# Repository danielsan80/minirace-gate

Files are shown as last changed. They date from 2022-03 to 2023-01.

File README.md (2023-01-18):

# Mini Race Challenge 3D printable parts

## Intro
This repository contains the 3D printable parts of the **Mini Race Challenge** Timing System.

It is a timing system specifically designed for extremely small sized radio controlled cars,
from 1:76 (Turbo Racing) to 1:57 (Coke Can Cars) and more.

More details on the site [www.miniracechallage.com](https://www.miniracechallenge.com).

The app is available at [app.miniracechallage.com](https://app.miniracechallenge.com)
and works on PC, IOS and Android.

This repository contains a few projects.

The project `gate` depends on the other ones.

`startlights` and `controller-box` are stand alone projects.

`ruler` and `car` are utilities.

## Contexts
The projects use a kind of framework.
You can find some directories that define the context:
- `src`: It contains the source code (*.scad) in an abstract/generic/default context.
  The 3d parts are located in a useful and natural position without a specific purpose.  
- `sim`: It contains modules useful for the simulation. These modules wrap and transform the source modules
  to translate and rotate them for a better placement in the space for a simulation purpose.
- `print`: It contains modules useful for the printing. These modules wrap and transform the source modules
  to translate and rotate them for a better placement in the space for a printing purpose.
- `test`: It contains modules useful for the testing. These modules cut or reduce the source
  modules to print drafts to test joints, plays, friction between parts and other test stuff.
  
## Conventions

Not all projects and parts still adopt the following conventions, but they are proving useful. 

### Private modules
To indicate a "private" module that is used only in the same file, it is prefixed with an underscore `_`.

A private module has a global scope too (with risk of name collision), but it helps to identify which modules in a file
should be considered "exported" and usable from who "< use >" the file.

### Context prefix
To specify a module belongs to a context it is prefixed with the context keyword (`print_*`, `sim_*`, `test_*`, ...).

### _transform suffix
To specify a module help to place a model in the right position (for a specific context for example)
it is suffixed with `_transform`. Obviously it has a `children()` instruction to which apply the transformation.

### _color suffix
To specify a module apply a color to a model (for a simulation for example)
it is suffixed with `_color`. Obviously it has a `children()` instruction to which apply the color.

# Index

[`controller-box`](controller-box/README.md): is the box to contain the controller card.

[`startlights`](startlights/README.md): Provides cover and hanger for the startlights card.
It provides a generic clip to hang the startlights and a metaclip to build a specific clip.

[`gate`](gate/README.md): Assembles the gate and the startlights together to simulate
and build the printable parts in stl files.
It adds the joint to hang up the startlights on the traverse.
It uses the rules to show the measures in the simulation context.
It uses the car models (1:54) to show the aspect ratio of the gate in the simulation context.

[`ruler`](ruler/README.md): is an utility to show rulers with some measures in simulation context.

[`car`](car/README.md): is an utility to show some cars in simulation context.

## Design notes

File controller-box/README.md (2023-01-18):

# Mini Race Challenge 3D printable parts: CONTROLLER BOX

This project provide the box to contain the controller.

The controller is the main timing system module card
to detect the passage of the cars on the start line.

## Getting started: easy way

Install [OpenSCAD](https://openscad.org/)

Download the project (Code -> Download ZIP) from [GitHub repository](https://github.com/danielsan80/minirace-gate).

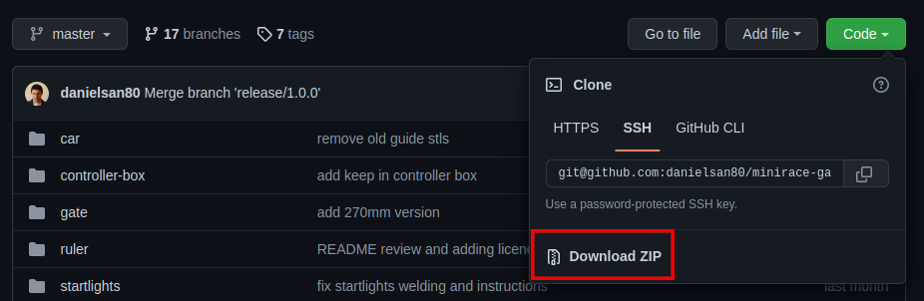
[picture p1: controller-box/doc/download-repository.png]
Download the project


Unzip the project in a directory (`<project-dir>`).

Find and open with OpenSCAD or with a text editor the file `<project-dir>/controller-box/config/parameters.scad`.

Change the parameters.

> for example your 3D printer may need a different play so you could change the `card_play`
> or any other `*_play` parameter.

After changing some parameter you can open with OpenSCAD the files in `<project-dir>/controller-box/build/scad/print`.

Then render the model (Design -> Render [F6]) and export it as STL (File -> Export -> Export as STL [F7])

That's all. Enjoy!

## Getting started: easy way for Linux users

Tested on Ubuntu 20.04.

You must have OpenSCAD (>=2019.05), ImageMagick and Git installed:

```
sudo apt-get install openscad imagemagick git
```

To build the gate you have to clone this project:

```
git clone git@github.com:danielsan80/minirace-gate.git
```

Enter the project dir:

```
cd minirace-gate
```

Enter in `controller-box` subdir:

```
cd controller-box
```

Now all should be ok.

### Rendering
The `<project-dir>/controller-box/build/scad/sim/*.scad` files are used to show a simulation of the whole controller box
and to generate the preview images.
You can play with these files or with a copy of them.

It is worth to grasp the whole idea.

The `<project-dir>/gate/build/scad/print/*.scad` files contain the single printable parts
and are used to generate the `*.stl` files at build time.

### Build

It's time to build the .stl files from the .scad files.

Run the build script:

```
bin/build
```

At the end of the build script running, you should have a new directory `<project-dir>/controller-box/build/stl`
with all updated .stl files

If you have to rebuild them you can clean up the build dir running

```
bin/cleanup
```

and rerun the `bin/build` script.

The dir `<project-dir>/gate/build/scad/print` contains the .scad version of the generated .stl files.

### Configuration

If you need to change the configuration you can edit the `gate/config/parameters.scad` file.

I tried to put all values in a parameter in this file. Tha major part of them should be considered as constants.

It makes sense to change only a few of them.

### Printing

I added a little [Printing guide](doc/printing.md) to help you to print the controller box.

The guide refers to the Thingiverse built .stl files.

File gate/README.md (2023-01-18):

# Mini Race Challenge 3D printable parts: GATE

This project assembles the gate and the startlights to simulate
and build the printable parts in stl files.
It adds the joint to hang up the startlights on the traverse.
It uses the rules to show the measures in the simulation context.
It uses the car models (1:54) to show the aspect ratio of the gate in the simulation context.

## Getting started: easy way

Install [OpenSCAD](https://openscad.org/)

Download the project (Code -> Download ZIP) from [GitHub repository](https://github.com/danielsan80/minirace-gate).

Download the project

Unzip the project in a directory (`<project-dir>`).

Create a link `<project-dir>/gate/vendor` -> `<project-dir>` 

Find and open with OpenSCAD or with a text editor the file `<project-dir>/gate/config/parameters.scad`.

Change the parameters.

> for example if you want to change the length of the traverse,
you must change the `startline_l` parameter, setting the distance (in millimeters) between the basements.

After changing some parameter you can open with OpenSCAD one of the files in `<project-dir>/gate/build/scad/print`.

> if you have changed the `startline_l` parameter you probably want to obtain the new stl traverse files:
> so open `<project-dir>/gate/build/scad/print/gate/traverse/traverse.scad`
> or one of his variants in `.../print/gate/traverse/variant/**/*.scad`.
 
Then render the model (Design -> Render [F6]) and export it as STL (File -> Export -> Export as STL [F7])

That's all. Enjoy!

## Getting started: easy way for Linux users

Tested on Ubuntu 20.04.

You must have OpenSCAD (>=2019.05), ImageMagick ang Git installed:

```
sudo apt-get install openscad imagemagick git
```

To build the gate you have to clone this project:

```
git clone git@github.com:danielsan80/minirace-gate.git
```

Enter the project dir:

```
cd minirace-gate
```

### Setup
After cloning the project from Github and moving into the project dir you must setup the project.

Enter in `gate` subdir:

```
cd gate
```

Run the setup script:

```
bin/setup
```

Now all should be ok.

### Rendering
The `<project-dir>/gate/build/scad/sim/*.scad` files are used to show a simulation of the whole gate
and to generate the preview images.
You can play with these files or with a copy of them.

It is worth to grasp the whole idea.

The `<project-dir>/gate/build/scad/print/*.scad` files contain the single printable parts
and are used to generate the `*.stl` files at build time. 

### Build

It's time to build the .stl files from the .scad files.

Run the build script:

```
bin/build
```

At the end of the build script running, you should have a new directory `gate/build/stl`
with all updated .stl files

If you have to rebuild them you can clean up the build dir running

```
bin/cleanup
```

and rerun the `bin/build` script. 

The dir `<project-dir>/gate/build/scad/print` contains the .scad version of the generated .stl files. 

### Configuration

If you need to change the configuration you can edit the `gate/config/parameters.scad` file.

I tried to put all values in a parameter in this file. Tha major part of them should be considered as constants.

It makes sense to change only a few of them. 

### Printing

The project has a lot of elements, so I added a little [Printing guide](doc/printing.md) to help you understanding it.

The guide refers to the Thingiverse built .stl files.

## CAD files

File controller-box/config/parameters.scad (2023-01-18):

$fn = 100;
fix = 0.01;
fix2 = 0.1;
a_lot = 1000;
a_few = 10;
layer_w = 0.46;
layer_h = 0.15;

box_wall_thick = 2.2;
box_wall_half_thick = box_wall_thick/2;
box_bottom_base_thick = 1;
box_top_base_thick = 1;

box_joint_h = 4;

box_joint_play = 0.20;
box_side_slide_play = 0.15;
box_joint_half_play = box_joint_play/2;

card_w = 36.5;
card_l = 83.5;
card_thick = 0.6;
card_z_offset = 1;
card_play = 0.25;
card_overhang_l = 8;
card_overhang_offset = 4.5;
card_overhang_w = 31;
card_left_margin = 2;
card_back_margin = 2;

chip_x = card_overhang_l+4;
chip_y = -8;
chip_l = 44+(chip_y*-1);
chip_w = 28;
chip_thick = 3.8 + 0.4;
chip_play = 0.3;
chip_z_offset = 0;//8.4;

card_keep_l = (card_w-chip_w)/2-chip_play*2;
card_central_keep_r = 2;

chip_connector_w = 7.5;
chip_connector_l = 5;
chip_connector_h = 2.8;
chip_connector_plugin_w = 10;
chip_connector_plugin_h = 7;

chip_connector_hole_frame_thick = 0.6;
chip_connector_hole_margin_w = 0.5;
chip_connector_hole_margin_h = 0.5;
chip_connector_hole_w = chip_connector_w+chip_connector_hole_margin_w*2;
chip_connector_hole_h = chip_connector_h+chip_connector_hole_margin_h*2;
chip_connector_hole_thick = 1.6;

chip_connector_inner_niche_margin_w = 0.5;
chip_connector_inner_niche_margin_h = 0.5;
chip_connector_inner_niche_w = chip_w+chip_connector_inner_niche_margin_w*2;
chip_connector_inner_niche_h = chip_thick+chip_connector_h+chip_connector_inner_niche_margin_h*2;
chip_connector_inner_niche_offset = 0.5;

chip_connector_outer_niche_margin_w = 0.5;
chip_connector_outer_niche_margin_h = 0.5;
chip_connector_outer_niche_w = chip_connector_plugin_w+chip_connector_outer_niche_margin_w*2;
chip_connector_outer_niche_h = chip_connector_plugin_h+chip_connector_outer_niche_margin_h*2;
chip_connector_outer_niche_offset = chip_play-chip_connector_inner_niche_offset+box_wall_thick-chip_connector_hole_thick;

chip_processor_w = 20;
chip_processor_l = 20;
chip_processor_thick = 7-chip_thick;
chip_processor_margin = 5;

startlights_connector_w = 3.6;
startlights_connector_l = 7.2;
startlights_connector_h = 5;
startlights_connector_pos = [card_overhang_l,43.31];

startlights_connector_old_w = 3.6;
startlights_connector_old_l = 10;
startlights_connector_old_h = 5;
startlights_connector_old_pos = [card_overhang_l,-startlights_connector_old_l/2+card_l-card_overhang_offset-card_overhang_w-4];

antenna_w = card_overhang_w;
antenna_play = 0.5;
antenna_thick = 0.5;
antenna_hole_thick = 1;
antenna_hole_w = antenna_w+antenna_play*2;
antenna_side_margin = card_overhang_offset;
antenna_start_margin = 2;
antenna_end_l = 15;
antenna_l = 198-antenna_end_l;

antenna_guide_thick = box_wall_half_thick;
//antenna_guide_side_margin = antenna_side_margin-antenna_play;
antenna_guide_play = antenna_play;
antenna_guides_gap_w = antenna_hole_w;
antenna_guides_gap_side_offset = card_left_margin+card_play+antenna_side_margin-antenna_play;



box_inner_l = card_left_margin+card_l+(chip_y*-1)+card_play+chip_play-chip_connector_inner_niche_offset;
box_inner_h = card_z_offset+card_thick+chip_z_offset+chip_thick+chip_connector_h+box_joint_h+chip_connector_hole_margin_h+chip_connector_hole_frame_thick;

box_outer_l = box_inner_l + box_wall_thick*2;
box_outer_h = box_inner_h + box_bottom_base_thick + box_top_base_thick;

box_inner_w = card_back_margin+card_w+card_overhang_l+antenna_start_margin+card_play*2;
box_outer_w = box_inner_w + box_wall_thick*2;

// CHIP LEDS

chip_led_hole_d = 4.5;
chip_led_hole_cap_d = 5;
chip_led_hole_cap_r = chip_led_hole_cap_d/2;
chip_led_hole_cap_inner_thick = 0.8;
chip_led_hole_cap_play = 0.12;
chip_led_hole_r = chip_led_hole_d/2;

chip_led_hole_tube_thick = 1;
chip_led_hole_tube_r = chip_led_hole_r+chip_led_hole_tube_thick;
chip_led_hole_tube_r_ext = 0.5;
chip_led_hole_tube_h1 = 3;
chip_led_hole_tube_h2 = 3.5;


// CHIP BLUE LED
chip_blue_led_hole_angle_pos = [-18,24];
chip_blue_led_hole_angle_pos_offset = [
    -chip_w-chip_x-card_play-antenna_start_margin-box_wall_thick+box_outer_w,
    -chip_y+card_l+card_play+card_left_margin+box_wall_thick-box_outer_l
];

chip_blue_led_angle_pos = [
    chip_blue_led_hole_angle_pos.x+chip_blue_led_hole_angle_pos_offset.x,
    chip_blue_led_hole_angle_pos.y+chip_blue_led_hole_angle_pos_offset.y
    ];



// CHIP RED LED
chip_red_led_hole_angle_pos = [
    chip_blue_led_hole_angle_pos.x-9.525,
    chip_blue_led_hole_angle_pos.y
];
chip_red_led_hole_angle_pos_offset = [
    -chip_w-chip_x-card_play-antenna_start_margin-box_wall_thick+box_outer_w,
    -chip_y+card_l+card_play+card_left_margin+box_wall_thick-box_outer_l
];

chip_red_led_angle_pos = [
    chip_red_led_hole_angle_pos.x+chip_red_led_hole_angle_pos_offset.x,
    chip_red_led_hole_angle_pos.y+chip_red_led_hole_angle_pos_offset.y
];


cylinder_joint_play = 0.20;
cylinder_joint_margin = 6;
cylinder_joint_r = 0.5;


nail_groove_margin = 6;
nail_groove_r = 0.5;

keep_w = 1;
keep_wall_thick= max(card_back_margin, card_left_margin); //1;
keep_h = card_z_offset;
keep_card_thick_play = 0.2;
keep_card_thick = card_thick+keep_card_thick_play;
keep_hold_r = 0.4;

box_front_center_keep_offset = [0,-1];

box_card_pos = [
    box_wall_thick+antenna_start_margin+card_play,
    box_wall_thick+(chip_y*-1)+chip_play-chip_connector_inner_niche_offset,
    box_bottom_base_thick+card_z_offset
];


startlights_cable_side_hole_w = 3;
startlights_cable_side_hole_h = 3;
startlights_cable_side_hole_pos = [box_card_pos.y+startlights_connector_pos.y,box_outer_h-box_top_base_thick-startlights_cable_side_hole_h/2-1];
//startlights_cable_side_hole_pos = [box_outer_l/2, box_outer_h/2];
startlights_cable_side_hole_play = box_joint_play;

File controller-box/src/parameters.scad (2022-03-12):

$fn = 100;
fix = 0.01;
fix2 = 0.1;
a_lot = 1000;
play1 = 0.15;
play2 = 0.20;
play3 = 0.25;

box_wall_thick = 2.2;
box_wall_half_thick = box_wall_thick/2;
box_bottom_base_thick = 1;
box_top_base_thick = 1;

box_joint_h = 4;

card_w = 44.5;
card_l = 91.5;
card_thick = 0.6;
card_z_offset = 2;
card_play = play1;

antenna_w = 35;
antenna_thick = 1.5;
antenna_side_margin = 3.5;

box_inner_w = card_w+card_play*2;
box_inner_l = card_l+card_play*2;
box_inner_h = 10;
//box_inner_w = 4;
//box_inner_l = 30;
//box_inner_h = 10;

box_outer_w = box_inner_w + box_wall_thick*2;
box_outer_l = box_inner_l + box_wall_thick*2;
box_outer_h = box_inner_h + box_bottom_base_thick + box_top_base_thick;

box_joint_play = play2;
box_side_slide_play = play1;
box_joint_half_play = box_joint_play/2;

cylinder_joint_play = play2;
cylinder_joint_margin = 6;
cylinder_joint_l = box_inner_w - cylinder_joint_margin*2 ;
cylinder_joint_r = 0.4;


nail_groove_margin = 6;
nail_groove_l = box_inner_w - nail_groove_margin*2 ;
nail_groove_r = 0.5;

rail_bottom_w = 1;
rail_top_right_r = 0.4;
rail_top_left_r = 0.15;

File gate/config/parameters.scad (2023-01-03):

$fn=100;
fix = 0.01;
fix2 = 0.1;
a_lot = 1000;
a_few = 10;
play = 0.25;
play2 = 0.15;
play3 = 0.20;
    layer_h = 0.15;
    layer_w = 0.46;
min_space = 0.198;

profile_w = 20;
profile_h = 2;

base_curvature_r = 2;

upright_base_w = 20;
upright_base_l = 47;
upright_base_h = 2.5;

angle_base_w = 20;
angle_base_l = 25;
angle_base_h = 2.5;
angle_base_h2_c = 0.5;

base_hole_margin = 0.3;

pylon_side = 13;

bar_w = 4;

bolt_d=6;
bolt_h=4;


reinforcement_gap = 5;
//reinforcement_gap = -5;

startline_l = 160; //80; //160; //270;
startline_l_160mm = 160;
startline_l_270mm = 270;

upright_h = 90; //40; //90;

upright_base_groove_thick = min_space;
upright_base_groove_depth = layer_h*2;
upright_base_hole_play = 0.15;

basement_upright_margin = 5;
basement_h = 10;

traverse_play = play2;

traverse_hook_l = 8;
traverse_hook_w = 2;
traverse_hook_thick = 0.8;
traverse_hooks_intra_space_l = 30;

bar_wrapper_w = 3;
bar_wrapper_thick = 1.2;
bar_wrapper_play = play2;

traverse_bar_wrappers_intra_space_l = (reinforcement_gap+pylon_side)*2;

ct_slide_side = 7;
ct_slide_play = play3;

v_slide_play = play2;

hanger_clip_junction_w = 2;
hanger_clip_junction_l = 4;

hanger_clip_generic_w = 5;

bolt_joint_play = 0.15;

stick_void_l_margin = 0.5;
stick_d = 2;
stick_play = 0.15;

traverse_stick_l = 30;
traverse_stick_void_l = traverse_stick_l + stick_void_l_margin*2;

upright_angle_joint_stick_l = 15;
upright_angle_joint_stick_void_l = upright_angle_joint_stick_l + stick_void_l_margin;

upright_angle_joint_button_r = bar_w/2;
upright_angle_joint_button_play = 0.25;
upright_angle_joint_button_h = 3;
upright_angle_joint_bar_top_w = 1;
upright_angle_joint_bar_top_play = 0.15;
upright_angle_joint_bar_bottom_h = angle_base_h*angle_base_h2_c;


bolting_base_thick = 0.5;

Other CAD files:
gate/src/parameters.scad
car/main.scad
car/src/car.scad
car/src/cars.scad
controller-box/build/scad/print/box/box_bottom.scad
controller-box/build/scad/print/box/box_side_slide.scad
controller-box/build/scad/print/box/box_top.scad
controller-box/build/scad/print/box/box_top_led_hole_cap.scad
controller-box/build/scad/sim/controller-box.scad
controller-box/main.scad
controller-box/src/functions.scad
controller-box/src/interparts/box_bottom-box_side_slide.scad
controller-box/src/interparts/box_bottom-box_top.scad
controller-box/src/joints/cylinder_joint.scad
controller-box/src/joints/keep.scad
controller-box/src/joints/nail_groove.scad
controller-box/src/parts/box_bottom.scad
controller-box/src/parts/box_side_slide.scad
controller-box/src/parts/box_top.scad
controller-box/src/parts/box_top_led_hole_cap.scad
controller-box/src/parts/print/box_bottom.scad
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

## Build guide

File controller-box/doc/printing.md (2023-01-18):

## Printing guide

### Intro

These are the main parts of the project:

- the controller box
- the led caps

Of course you can use the filament colors you prefer but
ideally the project is designed to be printed with this ones:

- **matte black** for the controller box
- **transparent** for the led caps

Here are some suggestions:

- **matte black**:  [Overture Matte Black pla filament](https://www.amazon.it/gp/product/B08X6YWZBT) [★★★★★].
- **transparent**:  [Giantarm Transparent pla filament](https://www.amazon.it/gp/product/B08LZ7L7L1) [★★★★☆]. You can avoid to print the led caps and use these [LED lampshade with light guide column cap](https://www.aliexpress.com/item/1005002316760848.html)

**No supports are needed**.

### Controller box

Printing the controller box is **the only thing required** to get started with MRC Timing system.

- box_bottom.stl (x 1) [**matte black**]
- box_side_slide.stl (x 1) [**matte black**]
- box_top.stl (x 1) [**matte black**]
- box_top_led_hole_cap (x 2) [**transparent**]

That's all!

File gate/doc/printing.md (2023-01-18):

## Printing guide

### Intro

These are the main parts of the project:

- the basements (blocks to place the gate on)
- the gate (uprights, angles and traverse)
- the boltings (bolts help you to place the gate on something other than the basements)
- the starglights (the cover to put on the startlights module)
- the hanger (clips and rod allow you to hang up the startlights module on the gate traverse).

Of course you can use only one filament colors and in case paint it but
ideally the project is designed to be printed in different ones:

- **cement gray** for the basements
- **silver** for the gate, the hanger clips and the boltings
- **matte black** for the startlights cover and the hanger rod

Here are some suggestions:

- **cement gray**: [Giantarm Silver pla filament](https://www.amazon.it/Filamento-GIANTARM-Stampante-Spool-Argento/dp/B07PV5KD6S) [★★★★☆]. It is a silver, not a gray, but we like it and is a good quality brand.
- **silver**: [Noulei Silk Silver pla filament](https://www.amazon.it/Noulei-Filamento-stampanti-Printing-Filament/dp/B07PRX7X4B) [★★★☆☆]. It is a silk silver, we like it but after a while we preferred to use [Giantarm Silver pla filament](https://www.amazon.it/Filamento-GIANTARM-Stampante-Spool-Argento/dp/B07PV5KD6S) [★★★★☆] because  is more strong and cohesive: it is not a silk pla but it is a better quality filament and the gate looks good.
- **matte black**:  [Overture Matte Black pla filament](https://www.amazon.it/gp/product/B08X6YWZBT) [★★★★★].

**No supports are needed**. The startlights rod has an integrated support to remove at post-printing time.

### Basements

Basements are created to convey the cars under the gate, preventing they crashed into the uprights.

To do this they should have a trapezoidal base, but currently they have a rectangular base.

With a rectangular base they are not so useful (they are a WIP).

Anyway, if you want to print this version...

- basement.stl (x 2) [**cement gray**]

### Bolting

If you want to place the gate on something other than the provided basements
or directly on the track you can print the boltings and glue them on it.

- bolting.stl (x 2) [**silver**]

> Note: right now the basement has not integrated bolts but it should in the future (it is a WIP).
> So, for now, you can glue the boltings on the basements too.

### Gate

You can print tha gate and place it on the basements or not: your choice.

- upright.stl (x 2) [**silver**]
- upright_stick.stl (x 8) [**silver**]

- angle.stl (x 2) [**silver**]

- traverse_L_160mm.stl (x 1) [**silver**]
- traverse_R_160mm.stl (x 1) [**silver**]
- traverse_stick_1of3.stl (x 2) [**silver**]
- traverse_stick_2of3.stl (x 2) [**silver**]
- traverse_stick_3of3.stl (x 2) [**silver**]

Optionally you can print the 270mm variant:

- ~~traverse_L_160mm.stl (x 1) [**silver**]~~
- ~~traverse_R_160mm.stl (x 1) [**silver**]~~
- traverse_L_270mm.stl (x 1) [**silver**]
- traverse_R_270mm.stl (x 1) [**silver**]

### Startlights

If you have the startlights module you need the cover to put on it:

- startlights.stl (x1) [**matte black**]

To hang it to the gate you need to print the hanger:

- hanger_rod (x1) [**matte black**]
- hanger_clip (x2) [**silver**]

There is a generic clip variant that allows you to hang the startlights on what you want (a 3-5mm thick bar for example)

- hanger_clip_generic (x2) [**matte black**]

That's all!

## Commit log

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2022-01-01 mv old gate in src
    [gaslands_gate.scad, gaslands_gate_sim.scad, gate.scad]
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2022-01-02 split in more then one file
    [angle-traverse.scad, angle.scad, bar.scad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]
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2022-01-08 ok tuning startlights hook
    [gate.scad, hook.scad, parameters.scad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]
2022-01-10 post print test 1
    [angle.scad, bolt_joint.scad, gate.scad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]
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2022-01-20 fix hook diameter
    [new_gate.scad, traverse-startlights.scad, traverse.scad]
2022-01-20 rename c_joint in ct_slide
    [bar_wrapper.scad, ct_slide.scad, hook.scad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]
2022-01-21 rn slide_joint => v_slide
    [angle-traverse.scad, hanger.scad, index.scad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]
2022-01-22 rename bar_c => hanger
    [gate.scad, hanger.scad, hanger_clip.scad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]
2022-01-22 mv hanger modules in parts/hanger*
    [hanger.scad, hanger_clip.scad, index.scad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]
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2022-01-22 split part from supports
    [hanger.scad, hanger_rod.scad, index.scad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]
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2022-01-23 fix startlights connector after vendor refactoring
    [board.scad, leds.scad, main.scad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]
2022-01-24 tuning button joint v1
    [button_joint.scad, main.scad, parameters.scad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]
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2022-01-27 ready to print test 2
    [angle.scad, bolt_joint.scad, ground-upright.scad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]
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2022-02-17 integrate controller box as basement
    [angle.scad, basement-ground.scad, basement_block.scad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]
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2022-02-22 review upright distance calculation
    [angle-traverse.scad, main.scad, new_gate.scad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]
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2022-02-23 rn upright_distance file and fix sim
    [angle-traverse.scad, main.scad, new_gate.scad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]
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2022-02-27 mv sim new/old gate
    [gate.scad, main.scad, new_gate.scad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]
2022-02-27 gate stuff in gate dir
    [angle-traverse.scad, angle.scad, bar.scad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]
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2022-03-02 add variant for traverse without basement
    [traverse.scad, traverse_without_basement.scad, traverse_without_basement_split_L.scad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]
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2022-03-30 mv parameters in config dir
    [box_block.scad, box_bottom-box_side_slide.scad, box_bottom-box_top.scad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]
2022-03-30 set controller size and add connector hole
    [box_bottom.scad, controller.scad, main.scad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]
2022-03-30 tuning controller box printing
    [basement_box.scad, box_bottom.scad, box_side_slide.scad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]
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2022-04-03 fix ruler
    [ruler.scad]
2022-04-04 add groove on basements
    [basement_block.scad, basement_block_with_hole.scad, basement_box.scad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]
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2022-04-04 ground has not variants
    [ground.scad, ground_base.scad, ground_basement_block_with_hole.scad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]
2022-04-04 restore box cylinder joint
    [box_bottom.scad, box_top.scad]
2022-04-06 fix layer_w
    [parameters.scad]
2022-04-07 review box post feedback
    [box_bottom.scad, box_side_slide.scad, functions.scad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]
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2022-04-07 fix startlight hook play
    [parameters.scad]
2022-04-09 fix antenna hole offset
    [box_bottom.scad]
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2022-04-09 box fixes
    [box_bottom.scad, box_side_slide.scad, box_top.scad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]
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2022-04-10 customizable terminal box width
    [box_bottom-box_side_slide.scad, box_bottom-box_top.scad, box_bottom.scad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]
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2022-04-11 fix card thick
    [parameters.scad]
2022-04-11 semplify upright-angle joint and add toothpick
    [button_joint.scad, main.scad, new_gate.scad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]
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2022-04-12 fix guides
    [box_bottom.scad, main.scad]
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2022-04-12 fix connector hole position
    [parameters.scad]
2022-04-12 fix connector hole pos
    [parameters.scad]
2022-04-13 fix cylinder joint
    [box_top.scad, main.scad]
2022-04-19 add welding groove to startlights mask
    [board.scad, main.scad, parameters.scad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]
2022-04-20 review welding groove for startlights
    [parameters.scad, startlights.scad]
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2022-04-21 add led tube and central keep to controller box
    [box_bottom.scad, box_top.scad, main.scad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]
2022-04-27 remove hanger hook play
    [parameters.scad, traverse.scad, traverse_split_toothpick.scad]
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2022-05-02 fix startlights welding
    [main.scad, new_gate.scad, parameters.scad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]
2022-05-02 add box hole cap
    [basement_box.scad, basement_box_controller_top.scad, basement_box_controller_top_with_groove.scad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]
2022-05-04 add keep in controller box
    [box_bottom.scad, keep.scad]
2022-05-04 add reinforcement to joint buttons
    [main.scad, new_gate.scad, parameters.scad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]
2022-05-06 add short stick
    [traverse.scad, traverse_split_toothpick_long.scad, traverse_split_toothpick_short.scad]
2022-05-07 WIP rm old vendor stl, add glue guide, export png
    [basement_box_top_glue_guide.scad, main.scad, new_gate.scad]
2022-05-10 remove old guide stls
    [car.scad, cars.scad, gate_on_basement.scad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]
2022-05-10 fix guides and sticks
    [basement_box_top_glue_guide.scad, basement_box_top_hole_cap.scad, basement_ground_guide.scad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]
2022-05-13 WIP on sims and guides
    [basement_box.scad, basement_ground_guide.scad, basement_ground_guides.scad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]
2022-05-13 fix guides and refactoring sim context
    [angle-traverse.scad, basement_box.scad, basement_ground_guide.scad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]
2022-05-19 review box cap ring r
    [basement_box.scad]
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2022-05-21 WIP renaming ground => bolting
    [basement_block.scad, basement_ground_guide.scad, basement_ground_guide_box_controller.scad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]
2022-05-21 DONE renaming ground => bolting
    [basement_bolting_guide.scad, basement_bolting_guide_box_controller.scad, basement_bolting_guide_box_terminal.scad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]
2022-05-21 rn toothpick => stick
    [parameters.scad, traverse.scad, traverse_split_stick_1of3.scad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]
2022-05-21 fix parse error
    [upright.scad]
2022-05-21 pull out underplace transfor
    [basement_bolting_guides.scad, basement_box.scad, gate_on_basement.scad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]
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2022-05-21 add traverse splits instructions
    [parameters.scad, traverse_splits_instructions.scad]
2022-05-22 add upright assemply instructions
    [traverse_assembly.scad]
2022-05-22 new upright assembly instructions, readme, build
    [traverse_assembly.scad, upright.scad, upright_assembly.scad]
2022-05-25 fix startlights welding and instructions
    [basement_bolting_guides.scad, parameters.scad]
2022-05-30 rn mode => startline_mode
    [angle-traverse.scad, angle.scad, basement_bolting_guides.scad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]
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2022-05-30 fix startline_l
    [basement_box.scad, bolting.scad, gate_on_basement.scad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]
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2022-06-24 remove remaining use new_gate.scad
    [traverse_assembly.scad, upright_assembly.scad]
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2022-07-03 review led hole and add a new hole
    [box_top.scad, controller.scad, main.scad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]
2022-07-06 move startlights connector and top hole on it WIP
    [basement_box.scad, box_bottom.scad, controller.scad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]
2022-07-08 tuning of bottom box after startlights connector position change
    [basement_bolting_guide.scad, basement_box.scad, box_bottom.scad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]
2022-07-09 add led holes in bolting guide
    [basement_bolting_guide.scad, parameters.scad, values.scad]
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2022-07-26 fix connector + move center
    [box_top.scad, controller.scad, parameters.scad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]
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2022-09-12 change controller top cap play for black matte pla
    [basement_box.scad, parameters.scad]
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2022-09-14 fix after phisical feedback
    [box_bottom.scad, controller.scad, main.scad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]
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
